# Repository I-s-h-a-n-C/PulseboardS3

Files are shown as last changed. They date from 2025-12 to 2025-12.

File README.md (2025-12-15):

# Pulseboard S3
This is an ESP32 S3 based Devboard, designed to be used in conjunction with EMGs and EKGs. As with all ESP32S3 Devboards, it has WiFi and Bluetooth capibilities.


## Features
* ESP32 S3 Microcontroller
* Wifi and Bluetooth
* Onboard Battery Charging
* Onboard temperature and moisture sensor
* 38 GPIO pins
* 3.3 and 5v
* USB-C Connectivity (Impedence matched)
* Status LEDS
* 4-layer PCB design

## PCB
### Schematic


### Layer 1 - Routing, Layer 2 - GND, Layer 3 - GND (mostly), Layer 4 - Routing


### Front


### Back


### Order



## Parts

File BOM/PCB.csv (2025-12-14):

Id | Designator | Footprint | Quantity | Designation | Supplier and ref
1 | RESET1,BOOT1 | SW_SPST_PTS810 | 2 | ~
2 | J1,J3 | PinHeader_1x22_P2.54mm_Vertical | 2 | ~
3 | U2 | Diodes_UDFN-10_1.0x2.5mm_P0.5mm | 1 | ESD7104MUTAG
4 | C5,C3,C4,C1 | C_0603_1608Metric | 4 | 0.1uF
5 | R1,R8,R2 | R_0603_1608Metric | 3 | 5.1k
6 | R5,R4,R3 | R_0603_1608Metric | 3 | 10k
7 | R6 | R_0603_1608Metric | 1 | 1M
8 | C6,C2,C7 | C_0603_1608Metric | 3 | 10uF
9 | D2 | LED_0603_1608Metric | 1 | LED
10 | JUSB1 | USB_C_Receptacle_GCT_USB4105-xx-A_16P_TopMnt_Horizontal | 1 | USB_C_Receptacle_USB2.0
11 | R7 | R_0603_1608Metric | 1 | 200k
12 | U3 | WSON-6-1EP_2x2mm_P0.65mm_EP1x1.6mm | 1 | TLV75801PDRV
13 | U4 | AMS_QFN-4-1EP_2x2mm_P0.95mm_EP0.7x1.6mm | 1 | ENS210
14 | D1 | LED_WS2812B_PLCC4_5.0x5.0mm_P3.2mm | 1 | WS2812B
15 | U1 | XCVR_ESP32-S3-MINI-1-N8 | 1 | ESP32-S3-MINI-1-N8

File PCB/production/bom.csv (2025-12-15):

Designator | Footprint | Quantity | Value | LCSC Part #
BOOT1, RESET1 | SW_SPST_PTS810 | 2 | ~
C1, C3, C4, C5 | 0603 | 4 | 0.1uF
C2, C6, C7 | 0603 | 3 | 10uF
D1 | LED_WS2812B_PLCC4_5.0x5.0mm_P3.2mm | 1 | WS2812B
D2 | 0603 | 1 | LED
J1, J3 | PinHeader_1x22_P2.54mm_Vertical | 2 | ~
JUSB1 | USB_C_Receptacle_GCT_USB4105-xx-A_16P_TopMnt_Horizontal | 1 | USB_C_Receptacle_USB2.0
R1, R2, R8 | 0603 | 3 | 5.1k
R3, R4, R5 | 0603 | 3 | 10k
R6 | 0603 | 1 | 1M
R7 | 0603 | 1 | 200k
U1 | XCVR_ESP32-S3-MINI-1-N8 | 1 | ESP32-S3-MINI-1-N8
U2 | Diodes_UDFN-10_1.0x2.5mm_P0.5mm | 1 | ESD7104MUTAG
U3 | WSON-6-1EP_2x2mm_P0.65mm_EP1x1.6mm | 1 | TLV75801PDRV
U4 | AMS_QFN-4-1EP_2x2mm_P0.95mm_EP0.7x1.6mm | 1 | ENS210

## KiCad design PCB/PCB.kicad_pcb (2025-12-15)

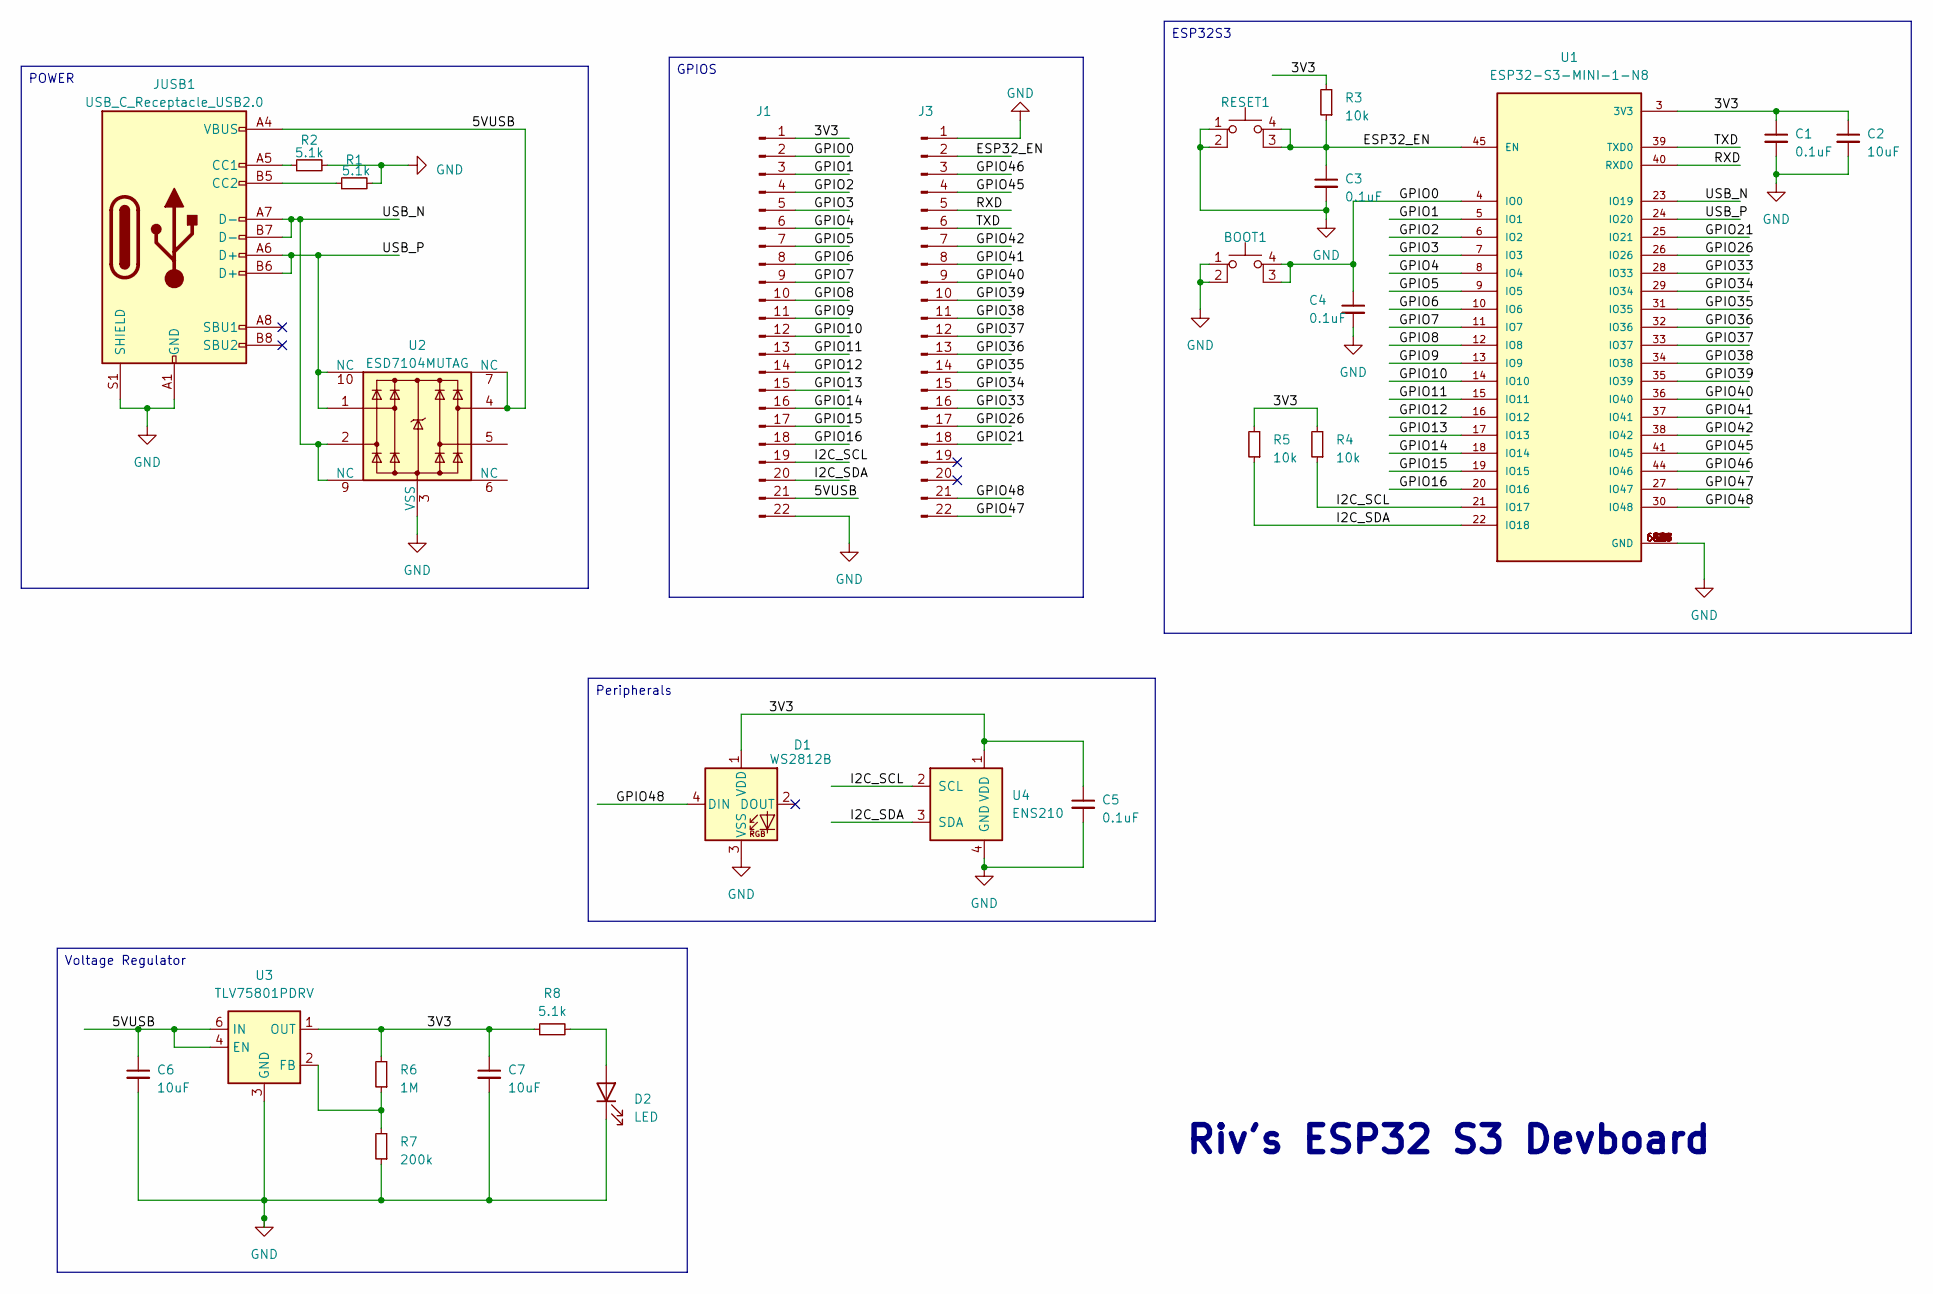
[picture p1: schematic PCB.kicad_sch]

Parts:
BOOT1: SW_SPST_PTS810
C1, C3, C4, C5: 0.1uF; C_0603_1608Metric
C2, C6, C7: 10uF; C_0603_1608Metric
D1: WS2812B; LED_WS2812B_PLCC4_5.0x5.0mm_P3.2mm
D2: LED; LED_0603_1608Metric
J1, J3: PinHeader_1x22_P2.54mm_Vertical
JUSB1: USB_C_Receptacle_USB2.0; USB_C_Receptacle_GCT_USB4105-xx-A_16P_TopMnt_Horizontal
R1, R2, R8: 5.1k; R_0603_1608Metric
R3, R4, R5: 10k; R_0603_1608Metric
R6: 1M; R_0603_1608Metric
R7: 200k; R_0603_1608Metric
RESET1: SW_SPST_PTS810
U1: ESP32-S3-MINI-1-N8; XCVR_ESP32-S3-MINI-1-N8; PARTREV v0.6
U2: ESD7104MUTAG; Diodes_UDFN-10_1.0x2.5mm_P0.5mm
U3: TLV75801PDRV; WSON-6-1EP_2x2mm_P0.65mm_EP1x1.6mm
U4: ENS210; AMS_QFN-4-1EP_2x2mm_P0.95mm_EP0.7x1.6mm

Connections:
/3V3: C1.1, C2.1, C5.1, C7.1, D1.1 (VDD), J1.1, R3.2, R4.2, R5.2, R6.2, R8.1, U1.3 (3V3), U3.1 (OUT), U4.1 (VDD)
/5VUSB: C6.1, J1.21, JUSB1.A4 (VBUS), JUSB1.A9 (VBUS), JUSB1.B4 (VBUS), JUSB1.B9 (VBUS), U2.4, U2.7 (NC), U3.4 (EN), U3.6 (IN)
/ESP32_EN: C3.1, J3.2, R3.1, RESET1.3 (K), RESET1.4 (A), U1.45 (EN)
/GPIO0: BOOT1.3 (K), BOOT1.4 (A), C4.1, J1.2, U1.4 (IO0)
/GPIO1: J1.3, U1.5 (IO1)
/GPIO2: J1.4, U1.6 (IO2)
/GPIO3: J1.5, U1.7 (IO3)
/GPIO4: J1.6, U1.8 (IO4)
/GPIO5: J1.7, U1.9 (IO5)
/GPIO6: J1.8, U1.10 (IO6)
/GPIO7: J1.9, U1.11 (IO7)
/GPIO8: J1.10, U1.12 (IO8)
/GPIO9: J1.11, U1.13 (IO9)
/GPIO10: J1.12, U1.14 (IO10)
/GPIO11: J1.13, U1.15 (IO11)
/GPIO12: J1.14, U1.16 (IO12)
/GPIO13: J1.15, U1.17 (IO13)
/GPIO14: J1.16, U1.18 (IO14)
/GPIO15: J1.17, U1.19 (IO15)
/GPIO16: J1.18, U1.20 (IO16)
/GPIO21: J3.18, U1.25 (IO21)
/GPIO26: J3.17, U1.26 (IO26)
/GPIO33: J3.16, U1.28 (IO33)
/GPIO34: J3.15, U1.29 (IO34)
/GPIO35: J3.14, U1.31 (IO35)
/GPIO36: J3.13, U1.32 (IO36)
/GPIO37: J3.12, U1.33 (IO37)
/GPIO38: J3.11, U1.34 (IO38)
/GPIO39: J3.10, U1.35 (IO39)
/GPIO40: J3.9, U1.36 (IO40)
/GPIO41: J3.8, U1.37 (IO41)
/GPIO42: J3.7, U1.38 (IO42)
/GPIO45: J3.4, U1.41 (IO45)
/GPIO46: J3.3, U1.44 (IO46)
/GPIO47: J3.22, U1.27 (IO47)
/GPIO48: D1.4 (DIN), J3.21, U1.30 (IO48)
/I2C_SCL: J1.19, R4.1, U1.21 (IO17), U4.2 (SCL)
/I2C_SDA: J1.20, R5.1, U1.22 (IO18), U4.3 (SDA)
/RXD: J3.5, U1.40 (RXD0)
/TXD: J3.6, U1.39 (TXD0)
/USB_N: JUSB1.A7 (D-), JUSB1.B7 (D-), U1.23 (IO19), U2.2, U2.9 (NC)
/USB_P: JUSB1.A6 (D+), JUSB1.B6 (D+), U1.24 (IO20), U2.1, U2.10 (NC)
GND: BOOT1.1, BOOT1.2, C1.2, C2.2, C3.2, C4.2, C5.2, C6.2, C7.2, D1.3 (VSS), D2.1 (K), J1.22, J3.1, JUSB1.A1 (GND), JUSB1.A12 (GND), JUSB1.B1 (GND), JUSB1.B12 (GND), JUSB1.S1 (SHIELD), R1.2, R2.2, R7.1, RESET1.1, RESET1.2, U1.1 (GND), U1.2 (GND), U1.42 (GND), U1.43 (GND), U1.46 (GND), U1.47 (GND), U1.48 (GND), U1.49 (GND), U1.50 (GND), U1.51 (GND), U1.52 (GND), U1.53 (GND), U1.54 (GND), U1.55 (GND), U1.56 (GND), U1.57 (GND), U1.58 (GND), U1.59 (GND), U1.60 (GND), U1.61 (GND), U1.61_1 (GND), U1.61_2 (GND), U1.61_3 (GND), U1.61_4 (GND), U1.61_5 (GND), U1.61_6 (GND), U1.61_7 (GND), U1.61_8 (GND), U1.62 (GND), U1.63 (GND), U1.64 (GND), U1.65 (GND), U2.3 (VSS), U2.8 (VSS), U3.3 (GND), U3.7 (GND), U4.4 (GND), U4.5 (GND)
unnamed: D2.2 (A), R8.2
unnamed: JUSB1.A5 (CC1), R2.1
unnamed: JUSB1.B5 (CC2), R1.1
unnamed: R6.1, R7.2, U3.2 (FB)

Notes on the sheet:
Riv's ESP32 S3 Devboard
Peripherals
POWER
Voltage Regulator
ESP32S3
GPIOS

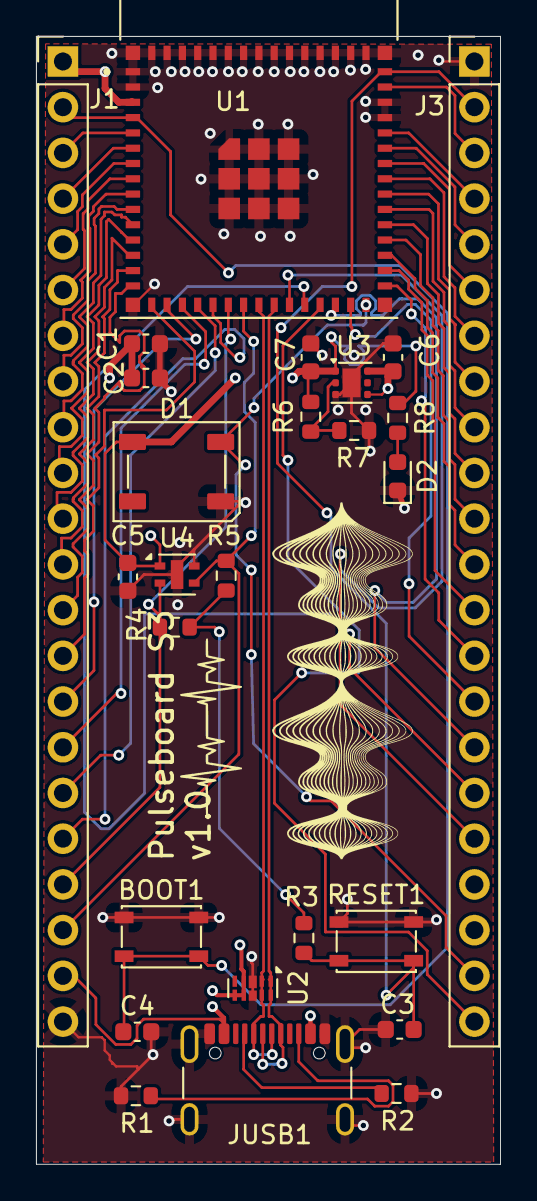
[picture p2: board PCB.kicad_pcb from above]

Board: 4 copper layers, 25.8 x 62.7 mm, 26 parts (0 on the bottom side), 47 nets.

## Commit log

2025-12-14 added the files for the board
    [PCB.kicad_pcb, PCB.kicad_sch]
2025-12-14 fixed mistake on impdence
    [PCB-B_Mask.gbs, PCB-B_Paste.gbp, PCB-B_Silkscreen.gbo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]
2025-12-15 added all needed files
    [PCB-B_Mask.gbs, PCB-B_Paste.gbp, PCB-B_Silkscreen.gbo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]
2025-12-15 fixed some stuff
    [PCB.kicad_pcb]
2025-12-15 Update README with features and PCB details
    Added detailed features and PCB information with images.
